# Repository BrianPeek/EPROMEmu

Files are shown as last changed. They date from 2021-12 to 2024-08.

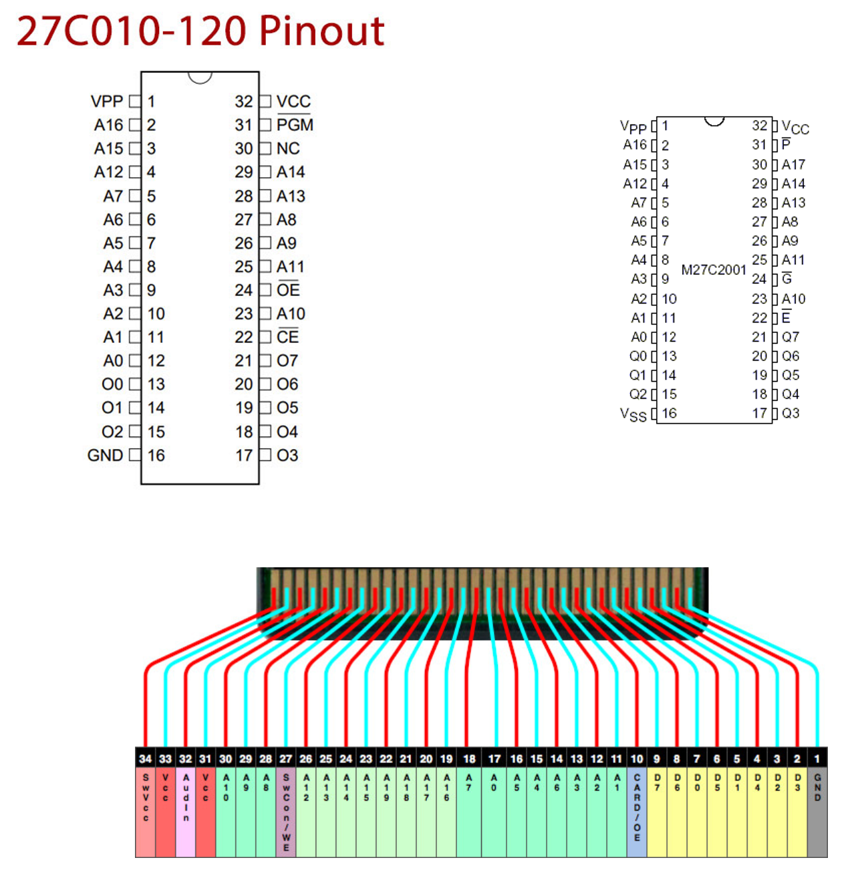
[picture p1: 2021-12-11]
other/pinouts.png

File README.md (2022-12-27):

# EPROMEmu

**!! WARNING: I have no idea what I'm doing !!**

I've decided to make this public in the rare event it might help someone.

This is a very simple, likely very wrong (EP)ROM emulator using a Teensy 4.1 and Arduino/PlatformIO.  It works for my purposes (emulating an EPROM for
use in an Atari Lynx EPROM cartridge), but it it is probably not the "correct" way to design hardware.  I have also used it on Game Gear and Vectrex EPROM cartridges,
but it was not heavily tested.

Please take caution with using anything you see here.  It's my first time using KiCad, my first time designing a PCB, and my first time creating hardware.  Again,
it works for my purposes, but perhaps it'll burn your house down.

Enjoy!

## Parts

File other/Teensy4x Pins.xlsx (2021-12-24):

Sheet: T4
Pin | Name | GPIO | Serial | I2C | SPI | PWM | CAN | Audio | XBAR | FlexIO | Analog | SD
0 | AD_B0_03 | 1.3 | Serial1(6) RX |  | SPI1(3) CS0 | PWM1_X1 | 2_RX |  | IO-17
1 | AD_B0_02 | 1.2 | Serial1(6) TX |  | SPI1(3) MISO | PWM1_X0 | 2_TX |  | IO-16
2 | EMC_04 | 4.4 |  |  |  | PWM4_A2 |  | 2:TX_DATA | IO-06 | 1:4
3 | EMC_05 | 4.5 |  |  |  | PWM4_B2 |  | 2:TX_SYNC | IO-07 | 1:5
4 | EMC_06 | 4.6 |  |  |  | PWM2_A0 |  | 2:TX_BCLK | IO-08 | 1:6
5 | EMC_08 | 4.8 |  |  |  | PWM2_A1 |  | 2:RX_DATA | IO-17 | 1:8
6 | B0_10 | 2.10 |  |  |  | PWM2_A2, QT4_1 |  | 1:TX3_RX1 |  | 2:10
7 | B1_01 | 2.17 | Serial2(4) RX |  |  | PWM1_B3 |  | 1:TX_DATA | IO-15 | 2:17, 3:17
8 | B1_00 | 2.16 | Serial2(4) TX |  |  | PWM1_A3 |  | 1:RX_DATA | IO-14 | 2:16, 3:16
9 | B0_11 | 2.11 |  |  |  | PWM2_B2, QT4_2 |  | 1:TX2_RX2 |  | 2:11
10 | B0_00 | 2.0 |  |  | SPI(4) CS0 | QT1_0 |  | MQS_RIGHT |  | 2:0
11 | B0_02 | 2.2 |  |  | SPI(4) MOSI | QT1_2 | 1_TX |  |  | 2:2
12 | B0_01 | 2.1 |  |  | SPI(4) MISO | QT1_1 |  | MQS_LEFT |  | 2:1
13 | B0_03 | 2.3 |  |  | SPI(4) SCK | QT2_0 | 1_RX |  |  | 2:3
14/A0 | AD_B1_02 | 1.18 | Serial3(2) TX |  |  | QT3_2 |  | SPDIF_OUT |  | 3:2 | A1:7, A2:7
15/A1 | AD_B1_03 | 1.19 | Serial3(2) RX |  |  | QT3_3 |  | SPDIF_IN |  | 3:3 | A1:8, A2:8
16/A2 | AD_B1_07 | 1.23 | Serial4(3) RX | Wire1(3) SCL |  |  |  | SPDIF_EXTCLK |  | 3:7 | A1:12, A2:12
17/A3 | AD_B1_06 | 1.22 | Serial4(3) TX | Wire1(3) SDA |  |  |  | SPDIF_LOCK |  | 3:6 | A1:11, A2:11
18/A4 | AD_B1_01 | 1.17 | Serial3(2) RTS | Wire(1) SDA |  | QT3_1 |  |  |  | 3:1 | A1:6, A2:6
19/A5 | AD_B1_00 | 1.16 | Serial3(2) CTS | Wire(1) SCL |  | QT3_0 |  |  |  | 3:0 | A1:5, A2:5
20/A6 | AD_B1_10 | 1.26 | Serial5(8) TX |  |  |  |  | 1:RX_SYNC |  | 3:10 | A1:15, A2:15
21/A7 | AD_B1_11 | 1.27 | Serial5(8) RX |  |  |  |  | 1:RX_BCLK |  | 3:11 | A1:0, A2:0
22/A8 | AD_B1_08 | 1.24 |  |  |  | PWM4_A0 | 1_TX |  |  | 3:8 | A1:13, A2:13
23/A9 | AD_B1_09 | 1.25 |  |  |  | PWM4_A1 | 1_RX | 1:MCLK |  | 3:9 | A1:14, A2:14
--- | ---- | ---- | ------ | --- | --- | --- | --- | ---- | ---- | ----- | ------
24/A10 | AD_B0_12 | 1.12 | Serial6(1) TX | Wire2(4) SCL |  | PWM1_X2 |  |  |  |  | A1:1
25/A11 | AD_B0_13 | 1.13 | Serial6(1) RX | Wire2(4) SDA |  | PWM1_X3 | GPT1_CLK |  |  |  | A1:2
26/A12 | AD_B1_14 | 1.30 |  |  | SPI1(3) MOSI |  |  | 1:TX_BCLK |  | 3:14 | A2:3
27/A13 | AD_B1_15 | 1.31 |  |  | SPI1(3) SCK |  |  | 1:TX_SYNC |  | 3:15 | A2:4
28 | EMC_32 | 3.18 | Serial7(7) RX |  |  | PWM3_B1
29 | EMC_31 | 4.31 | Serial7(7) TX |  | SPI2(1) CS1 | PWM3_A1
30 | EMC_37 | 3.23 |  |  |  | GPT1_3 | 3_RX | 3:MCLK | IO-23
31 | EMC_36 | 3.22 |  |  |  | GPT1_2 | 3_TX | 3:TX_DATA | IO-22
32 | B0_12 | 2.12 |  |  |  |  |  | 1:TX1_RX3 | IO-10 | 2:12
33 | EMC_07 | 4.7 |  |  |  | PWM2_B0 |  | 2:MCLK | IO-09 | 1:7
34 | SD_B0_03 | 3.15 | Serial5(8) RTS |  | SPI2(1) MISO | PWM1_B1 |  |  | IO-07 |  |  | DATA1
35 | SD_B0_02 | 3.14 | Serial5(8) CTS |  | SPI2(1) MOSI | PWM1_A1 |  |  | IO-06 |  |  | DATA0
36 | SD_B0_01 | 3.13 |  | Wire1(3) SDA | SPI2(1) CS0 | PWM1_B0 |  |  | IO-05 |  |  | CLK
37 | SD_B0_00 | 3.12 |  | Wire1(3) SCL | SPI2(1) SCK | PWM1_A0 |  |  | IO-04 |  |  | CMD
38 | SD_B0_05 | 3.17 | Serial5(8) RX |  | SPI2(1) B_DQS | PWM1_B2 |  |  | IO-09 |  |  | DATA3
39 | SD_B0_04 | 3.16 | Serial5(8) TX |  | SPI2(1) B_SSO_B | PWM1_A2 |  |  | IO-08 |  |  | DATA2

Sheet: T4 - GPIO
Pin | Name | GPIO | Serial | I2C | SPI | PWM | CAN | Audio | XBAR | FlexIO | Analog | SD
1 | AD_B0_02 | 1.02 | Serial1(6) TX |  | SPI1(3) MISO | PWM1_X0 | 2_TX |  | IO-16
0 | AD_B0_03 | 1.03 | Serial1(6) RX |  | SPI1(3) CS0 | PWM1_X1 | 2_RX |  | IO-17
24/A10 | AD_B0_12 | 1.12 | Serial6(1) TX | Wire2(4) SCL |  | PWM1_X2 |  |  |  |  | A1:1
25/A11 | AD_B0_13 | 1.13 | Serial6(1) RX | Wire2(4) SDA |  | PWM1_X3 | GPT1_CLK |  |  |  | A1:2
19/A5 | AD_B1_00 | 1.16 | Serial3(2) CTS | Wire(1) SCL |  | QT3_0 |  |  |  | 3:0 | A1:5, A2:5
18/A4 | AD_B1_01 | 1.17 | Serial3(2) RTS | Wire(1) SDA |  | QT3_1 |  |  |  | 3:1 | A1:6, A2:6
14/A0 | AD_B1_02 | 1.18 | Serial3(2) TX |  |  | QT3_2 |  | SPDIF_OUT |  | 3:2 | A1:7, A2:7
15/A1 | AD_B1_03 | 1.19 | Serial3(2) RX |  |  | QT3_3 |  | SPDIF_IN |  | 3:3 | A1:8, A2:8
17/A3 | AD_B1_06 | 1.22 | Serial4(3) TX | Wire1(3) SDA |  |  |  | SPDIF_LOCK |  | 3:6 | A1:11, A2:11
16/A2 | AD_B1_07 | 1.23 | Serial4(3) RX | Wire1(3) SCL |  |  |  | SPDIF_EXTCLK |  | 3:7 | A1:12, A2:12
22/A8 | AD_B1_08 | 1.24 |  |  |  | PWM4_A0 | 1_TX |  |  | 3:8 | A1:13, A2:13
23/A9 | AD_B1_09 | 1.25 |  |  |  | PWM4_A1 | 1_RX | 1:MCLK |  | 3:9 | A1:14, A2:14
20/A6 | AD_B1_10 | 1.26 | Serial5(8) TX |  |  |  |  | 1:RX_SYNC |  | 3:10 | A1:15, A2:15
21/A7 | AD_B1_11 | 1.27 | Serial5(8) RX |  |  |  |  | 1:RX_BCLK |  | 3:11 | A1:0, A2:0
26/A12 | AD_B1_14 | 1.30 |  |  | SPI1(3) MOSI |  |  | 1:TX_BCLK |  | 3:14 | A2:3
27/A13 | AD_B1_15 | 1.31 |  |  | SPI1(3) SCK |  |  | 1:TX_SYNC |  | 3:15 | A2:4
10 | B0_00 | 2.00 |  |  | SPI(4) CS0 | QT1_0 |  | MQS_RIGHT |  | 2:0
12 | B0_01 | 2.01 |  |  | SPI(4) MISO | QT1_1 |  | MQS_LEFT |  | 2:1
11 | B0_02 | 2.02 |  |  | SPI(4) MOSI | QT1_2 | 1_TX |  |  | 2:2
13 | B0_03 | 2.03 |  |  | SPI(4) SCK | QT2_0 | 1_RX |  |  | 2:3
6 | B0_10 | 2.10 |  |  |  | PWM2_A2, QT4_1 |  | 1:TX3_RX1 |  | 2:10
9 | B0_11 | 2.11 |  |  |  | PWM2_B2, QT4_2 |  | 1:TX2_RX2 |  | 2:11
32 | B0_12 | 2.12 |  |  |  |  |  | 1:TX1_RX3 | IO-10 | 2:12
8 | B1_00 | 2.16 | Serial2(4) TX |  |  | PWM1_A3 |  | 1:RX_DATA | IO-14 | 2:16, 3:16
7 | B1_01 | 2.17 | Serial2(4) RX |  |  | PWM1_B3 |  | 1:TX_DATA | IO-15 | 2:17, 3:17
37 | SD_B0_00 | 3.12 |  | Wire1(3) SCL | SPI2(1) SCK | PWM1_A0 |  |  | IO-04 |  |  | CMD
36 | SD_B0_01 | 3.13 |  | Wire1(3) SDA | SPI2(1) CS0 | PWM1_B0 |  |  | IO-05 |  |  | CLK
35 | SD_B0_02 | 3.14 | Serial5(8) CTS |  | SPI2(1) MOSI | PWM1_A1 |  |  | IO-06 |  |  | DATA0
34 | SD_B0_03 | 3.15 | Serial5(8) RTS |  | SPI2(1) MISO | PWM1_B1 |  |  | IO-07 |  |  | DATA1
39 | SD_B0_04 | 3.16 | Serial5(8) TX |  | SPI2(1) B_SSO_B | PWM1_A2 |  |  | IO-08 |  |  | DATA2
38 | SD_B0_05 | 3.17 | Serial5(8) RX |  | SPI2(1) B_DQS | PWM1_B2 |  |  | IO-09 |  |  | DATA3
28 | EMC_32 | 3.18 | Serial7(7) RX |  |  | PWM3_B1
31 | EMC_36 | 3.22 |  |  |  | GPT1_2 | 3_TX | 3:TX_DATA | IO-22
30 | EMC_37 | 3.23 |  |  |  | GPT1_3 | 3_RX | 3:MCLK | IO-23
2 | EMC_04 | 4.04 |  |  |  | PWM4_A2 |  | 2:TX_DATA | IO-06 | 1:4
3 | EMC_05 | 4.05 |  |  |  | PWM4_B2 |  | 2:TX_SYNC | IO-07 | 1:5
4 | EMC_06 | 4.06 |  |  |  | PWM2_A0 |  | 2:TX_BCLK | IO-08 | 1:6
33 | EMC_07 | 4.07 |  |  |  | PWM2_B0 |  | 2:MCLK | IO-09 | 1:7
5 | EMC_08 | 4.08 |  |  |  | PWM2_A1 |  | 2:RX_DATA | IO-17 | 1:8
29 | EMC_31 | 4.31 | Serial7(7) TX |  | SPI2(1) CS1 | PWM3_A1

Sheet: T4 card like
Audio | Prop | Native | GPIO | Audio | FlexIO | Xbar | I2C | CAN | SPI | Serial | Analog | PWM | Digital |  |  | Digital | PWM | Analog | Serial | SPI | CAN | I2C | Xbar | FlexIO | Audio | GPIO | Native | Prop | Audio
G | GND |  |  |  |  |  |  |  |  |  | GND |  |  |  |  | Vin |  |  |  |  |  |  |  |  |  |  |  | 5V
 |  | AD_B0_03 | 1.3 |  |  | 17 |  | RX2 | CS1 | RX1 |  | 1X1 | 0 |  |  | GND |  |  |  |  |  |  |  |  |  |  |  | G | G
 |  | AD_B0_02 | 1.2 |  |  | 16 |  | TX2 | MISO1 | TX1 |  | 1X0 | 1 |  |  | 3.3V 250mA max |  |  |  |  |  |  |  |  |  |  |  | 3V | 3.3
 | S | EMC_04 | 4.4 | O2 | 1:4 | 6 |  |  |  |  |  | 4A2 | 2 |  |  | 23 | 4A1 | A9 |  |  | RX1 |  |  | 3:9 | MCL1 | 1.25 | AD-B1_09 |  | A
M |  | EMC_05 | 4.5 | LR2 | 1:5 | 7 |  |  |  |  |  | 4B2 | 3 |  |  | 22 | 4A0 | A8 |  |  | TX1 |  |  | 3:08:00 |  | 1.24 | AD_B1_08
A |  | EMC_06 | 4.6 | BCL2 | 1:6 | 8 |  |  |  |  |  | 2A0 | 4 |  |  | 21 |  | A7 | RX5 |  |  |  |  | 3:11:00 | BCL1 | 1.27 | AD_B1_11 |  | A
A | A-EN | EMC_08 | 4.8 | IN2 | 1:8 | 17 |  |  |  |  |  | 2A1 | 5 |  |  | 20 |  | A6 | TX5 |  |  |  |  | 3:10:00 | LRC1 | 1.26 | AD_B1_10 |  | A
 | M-CS | B0_10 | 2.10 | O1D | 2:10 |  |  |  |  |  |  | 2A2, Q41 | 6 |  |  | 19 | Q30 | A5 | CTS3 |  |  | SCL0 |  | 3:00:00 |  | 1.16 | AD_B1_00 | S | C
 | L-EN | B1_01 | 2.17 | O1A | 2:17, 3:17 | 15 |  |  |  | RX2 |  | 1B3 | 7 |  |  | 18 | Q31 | A4 |  |  |  | SDA0 |  | 3:01:00 |  | 1.17 | AD_B1_01 | S | C
 |  | B1_00 | 2.16 | IN1 | 2:16, 3:16 | 14 | sda0 |  |  | TX2 |  | 1A3 | 8 |  |  | 17 |  | A3 | TX4 |  |  | SDA1 |  | 3:06:00 |  | 1.22 | AD_B1_06
 |  | B0_11 | 2.11 | O1C | 2:11 |  |  |  |  |  |  | 2B2,Q42 | 9 |  |  | 16 |  | A2 | RX4 |  |  | SCL1 |  | 3:07:00 |  | 1.23 | AD_B1_07
S |  | B0_00 | 2.0 | MQR | 2:0 |  |  |  | CS0 |  |  | Q10 | 10 |  |  | 15 | Q33 | A1 | RX3 |  |  |  |  | 3:03:00 | SPDI | 1.19 | AD_B1_03 |  | V
SM | M/L | B0_02 | 2.2 |  | 2:2 |  |  | TX1 | MOSI0 |  |  | Q12 | 11 |  |  | 14 | Q32 | A0 | TX3 |  |  |  |  | 3:02:00 | SPDO | 1.18 | AD_B1_02
SM | M | B0_01 | 2.1 | MQL | 2:1 |  |  |  | MISO0 |  |  | Q11 | 12 |  |  | 13 | Q20 | LED |  | SCK0 | rx1 |  |  | 2:03:00 |  | 2.3 | B0_03 | M | SM
 |  |  |  |  |  |  |  |  |  | Bottom SMT Pins
 |  | AD_B0_12 | 1.12 |  |  |  | SCL2 |  |  | TX6 | A10-1 | 1X2 | 24 |  |  | 25 | 1X3 | A11-1 | RX6 |  |  | SDA2 |  |  |  | 1.13 | AD_B0_13
 |  | AD_B1_14 | 1.30 |  | 3:14 |  |  |  | MOSI1 |  | A12-2 |  | 26 |  |  | 27 |  | A13-2 |  | SCK1 |  |  |  | 3:15 |  | 1.31 | AD_B1_15
 |  | EMC_32 | 3.18 |  |  |  |  |  |  | RX7 |  | 3B1 | 28 |  |  | 29 | 3A1 |  | TX7 |  |  |  |  |  |  | 4.31 | EMC_31
 |  | EMC_37 | 3.23 |  |  | 23 |  | RX3 |  |  |  | G13 | 30 |  |  | 31 | G12 |  |  |  | TX3 |  | 22 |  |  | 3.22 | EMC_36
 |  | B0_12 | 2.12 | O1B | 2:12:00 | 10 |  |  |  |  |  |  | 32 |  |  | 33 | 2B0 |  |  |  | TX1 |  | 9 | 1:7 | MCL2 | 4.7 | EMC_07
 |  |  |  |  |  |  |  |  |  | Bottom SDIO Pins
 |  | SD_B0_03 | 3.15 |  | DATA1 | 7 |  |  | MISO2 |  |  | 1B1 | 34 | ______| | |_____
 |  | SD_B0_02 | 3.14 |  | DATA0 | 6 |  |  | MOSI2 | CTS5 |  | 1A1 | 35 | _______| | |_______
 |  |  |  |  |  |  |  |  |  |  | GND |  |  | _________| | |_______
 |  | SD_B0_01 | 3.13 |  | CLK | 5 | SDA1 |  | CS2 |  |  | 1B0 | 36 | __________| | |___________
 |  |  |  |  |  |  |  |  |  |  | 3.3V 250mA max
 |  | SD_B0_00 | 3.12 |  | CMD | 4 | SCL1 |  | SCK2 |  |  | 1A0 | 37
 |  | SD_B0_05 | 3.17 |  | DATA3 | 9 |  |  |  | RX5 |  | 1B2 | 38
 |  | SD_B0_04 | 3.16 |  | DATA2 | 8 |  |  |  | TX5 |  | 1A2 | 39

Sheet: T4.1
Pin | Name | GPIO | Serial | I2C | SPI | PWM | CAN | Audio | XBAR | FlexIO | Analog | SD/CSI/LCD
0 | AD_B0_03 | 1.3 | Serial1(6) RX |  | SPI1(3) CS0 | PWM1_X1 | 2_RX |  | IO-17
1 | AD_B0_02 | 1.2 | Serial1(6) TX |  | SPI1(3) MISO | PWM1_X0 | 2_TX |  | IO-16
2 | EMC_04 | 4.4 |  |  |  | PWM4_A2 |  | 2:TX_DATA | IO-06 | 1:4
3 | EMC_05 | 4.5 |  |  |  | PWM4_B2 |  | 2:TX_SYNC | IO-07 | 1:5
4 | EMC_06 | 4.6 |  |  |  | PWM2_A0 |  | 2:TX_BCLK | IO-08 | 1:6
5 | EMC_08 | 4.8 |  |  |  | PWM2_A1 |  | 2:RX_DATA | IO-17 | 1:8
6 | B0_10 | 2.10 |  |  |  | PWM2_A2, QT4_1 |  | 1:TX3_RX1 |  | 2:10
7 | B1_01 | 2.17 | Serial2(4) RX |  |  | PWM1_B3 |  | 1:TX_DATA | IO-15 | 2:17, 3:17
8 | B1_00 | 2.16 | Serial2(4) TX |  |  | PWM1_A3 |  | 1:RX_DATA | IO-14 | 2:16, 3:16
9 | B0_11 | 2.11 |  |  |  | PWM2_B2,QT4_2 |  | 1:TX2_RX2 |  | 2:11
10 | B0_00 | 2.0 |  |  | SPI(4) CS0 | QT1_0 |  | MQS_RIGHT |  | 2:0
11 | B0_02 | 2.2 |  |  | SPI(4) MOSI | QT1_2 | 1_TX |  |  | 2:2
12 | B0_01 | 2.1 |  |  | SPI(4) MISO | QT1_1 |  | MQS_LEFT |  | 2:1
13 | B0_03 | 2.3 |  |  | SPI(4) SCK | QT2_0 | 1_RX |  |  | 2:3
14/A0 | AD_B1_02 | 1.18 | Serial3(2) TX |  |  | QT3_2 |  | SPDIF_OUT |  | 3:2 | A1:7, A2:7
15/A1 | AD_B1_03 | 1.19 | Serial3(2) RX |  |  | QT3_3 |  | SPDIF_IN |  | 3:3 | A1:8, A2:8
16/A2 | AD_B1_07 | 1.23 | Serial4(3) RX | Wire1(3) SCL |  |  |  | SPDIF_EXTCLK |  | 3:7 | A1:12, A2:12 | CSI_HSYNC
17/A3 | AD_B1_06 | 1.22 | Serial4(3) TX | Wire1(3) SDA |  |  |  | SPDIF_LOCK |  | 3:6 | A1:11, A2:11 | CSI_VSYNC
18/A4 | AD_B1_01 | 1.17 | Serial3(2) RTS | Wire(1) SDA |  | QT3_1 |  |  |  | 3:1 | A1:6, A2:6
19/A5 | AD_B1_00 | 1.16 | Serial3(2) CTS | Wire(1) SCL |  | QT3_0 |  |  |  | 3:0 | A1:5, A2:5
20/A6 | AD_B1_10 | 1.26 | Serial5(8) TX |  |  |  |  | 1:RX_SYNC |  | 3:10 | A1:15, A2:15 | CSI_D7
21/A7 | AD_B1_11 | 1.27 | Serial5(8) RX |  |  |  |  | 1:RX_BCLK |  | 3:11 | A1:0, A2:0 | CSI_D6
22/A8 | AD_B1_08 | 1.24 |  |  |  | PWM4_A0 | 1_TX |  |  | 3:8 | A1:13, A2:13 | CSI_D9
23/A9 | AD_B1_09 | 1.25 |  |  |  | PWM4_A1 | 1_RX | 1:MCLK |  | 3:9 | A1:14, A2:14 | CSI_D8
--- | ---- | ---- | ------ | --- | --- | --- | --- | ---- | ---- | ----- | ------
24/A10 | AD_B0_12 | 1.12 | Serial6(1) TX | Wire2(4) SCL |  | PWM1_X2 |  |  |  |  | A1:1
25/A11 | AD_B0_13 | 1.13 | Serial6(1) RX | Wire2(4) SDA |  | PWM1_X3 | GPT1_CLK |  |  |  | A1:2
26/A12 | AD_B1_14 | 1.30 |  |  | SPI1(3) MOSI |  |  | 1:TX_BCLK |  | 3:14 | A2:3 | CSI_D3
27/A13 | AD_B1_15 | 1.31 |  |  | SPI1(3) SCK |  |  | 1:TX_SYNC |  | 3:15 | A2:4 | CSI_D2
28 | EMC_32 | 3.18 | Serial7(7) RX |  |  | PWM3_B1
29 | EMC_31 | 4.31 | Serial7(7) TX |  | SPI2(1) CS1 | PWM3_A1
30 | EMC_37 | 3.23 |  |  |  | GPT1_3 | 3_RX | 3:MCLK | IO-23
31 | EMC_36 | 3.22 |  |  |  | GPT1_2 | 3_TX | 3:TX_DATA | IO-22
32 | B0_12 | 2.12 |  |  |  |  |  | 1:TX1_RX3 | IO-10 | 2:12
33 | EMC_07 | 4.7 |  |  |  | PWM2_B0 |  | 2:MCLK | IO-09 | 1:7
34 | B1_13 | 2.29 | Serial8(5) RX |  |  |  |  |  |  | 2:29,3:29
35 | B1_12 | 2.28 | Serial8(5) TX |  |  |  |  |  |  | 2:28,3:28
36 | B1_02 | 2.18 |  |  | SPI(4) CS2 | PWM2_A3 |  | 1:TX_BCLK | IO-16 | 2:18,3:18
37 | B1_03 | 2.19 |  |  | SPI(4) CS1 | PWM2_B3 |  | 1:TX_SYNC | IO-17 | 2:19,3:19
38/A14 | AD_B1_12 | 1.28 |  |  | SPI1(3) CS0 |  |  | 1:rx_data |  | 3:12 | A2:1 | CSI_D5
39/A5 | AD_B1_13 | 1.29 |  |  | SPI1(3) MISO |  |  | 1:tx_data |  | 3:13 | A2:2 | CSI_D4
40/A16 | AD_B1_04 | 1.20 |  |  |  |  |  |  |  | 3:4 | A1:9,A2:9 | CSI_PIXCLK
41/A17 | AD_B1_05 | 1.21 |  |  |  | GPT2_1 |  |  |  | 3:5 | A1:10,A2:10 | CSI_MCLK
SD Pins - Cable connector(T4 34-39)
42 | SD_B0_03 | 3.15 | Serial5(8) RTS |  | SPI2(1) MISO | PWM1_B1 |  |  | IO-07 |  |  | DATA1
43 | SD_B0_02 | 3.14 | Serial5(8) CTS |  | SPI2(1) MOSI | PWM1_A1 |  |  | IO-06 |  |  | DATA0
44 | SD_B0_01 | 3.13 |  | Wire1(3) SDA | SPI2(1) CS0 | PWM1_B0 |  |  | IO-05 |  |  | CLK
45 | SD_B0_00 | 3.12 |  | Wire1(3) SCL | SPI2(1) SCK | PWM1_A0 |  |  | IO-04 |  |  | CMD
46 | SD_B0_05 | 3.17 | Serial5(8) RX |  | FLEXSPI B_DQS | PWM1_B2 |  |  | IO-09 |  |  | DATA3
47 | SD_B0_04 | 3.16 | Serial5(8) TX |  | FLEXSPI B_SSO_B | PWM1_A2 |  |  | IO-08 |  |  | DATA2
Bottom Memory Connectors
48 | EMC_24 | 4:24 | Serial8(5) RX |  | FLEXSPI2_A_SS0_B | PWM1_B0
49 | EMC_27 | 4:27 | Serial8(5) RTS |  | FLEXSPI2_A_DATA01, SPI2(1) SCK | PWM1_A2 |  |  |  | 1:13
50 | EMC_28 | 4:28 | Serial8(5) CTS |  | FLEXSPI2_A_DATA02, SPI2(1) MOSI | PWM1_B2 |  |  |  | 1:14
51 | EMC_22 | 4:22 |  | Wire1(3) SCL | FLEXSPI2_A_SS1_B | PWM3_B3, QT2_3
52 | EMC_26 | 4:26 | Serial1(6) RX |  | FLEXSPI2_A_DATA00 | PWM1_B1 |  |  |  | 1:12
53 | EMC_25 | 4:25 | Serial1(6) TX |  | FLEXSPI2_A_SCLK | PWM1_A1
54 | EMC_29 | 4:29 | Serial1(6) RTS |  | FLEXSPI2_A_DATA03, SPI2(1) MISO | PWM3_A0 |  |  |  | 1:15

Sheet: T4.1 MUX
Pin | Name | ALT0 | ALt1 | ALT2 | ALT3 | ALT4 | Alt5 | ALT6 | ALT7 | ALT8 | ALT9
0 | AD_B0_03 | FLEXCAN2_RX | XBAR1_INOUT17 | LPUART6_RX | USB_OTG1_OC | FLEXPWM1_PWMX01 | GPIO1_IO03 | REF_CLK_24M | LPSPI3_PCS0
1 | AD_B0_02 | FLEXCAN2_TX | XBAR1_INOUT16 | LPUART6_TX | USB_OTG1_PWR | LEXPWM1_PWMX0 | GPIO1_IO02 | LPI2C1_HREQ | LPSPI3_SDI
2 | EMC_04 | SEMC_DATA04 | FLEXPWM4_PWMA02 | SAI2_TX_DATA | XBAR1_INOUT06 | FLEXIO1_FLEXIO04 | GPIO4_IO04
3 | EMC_05 | SEMC_DATA05 | FLEXPWM4_PWMB0 | SAI2_TX_SYNC | XBAR1_INOUT07 | FLEXIO1_FLEXIO05 | GPIO4_IO05
4 | EMC_06 | SEMC_DATA06 | FLEXPWM2_PWMA00 | SAI2_TX_BCLK | XBAR1_INOUT08 | FLEXIO1_FLEXIO06 | GPIO4_IO06
5 | EMC_08 | SEMC_DM00 | FLEXPWM2_PWMA01 | SAI2_RX_DATA | XBAR1_INOUT17 | FLEXIO1_FLEXIO08 | GPIO4_IO08
6 | B0_10 | LCD_DATA06 | QTIMER4_TIMER1 | FLEXPWM2_PWMA02 | SAI1_TX_DATA03 | FLEXIO2_FLEXIO10 | GPIO2_IO10 | SRC_BOOT_CFG06 |  | ENET2_CRS
7 | B1_01 | LCD_DATA13 | XBAR1_INOUT15 | LPUART4_RX | SAI1_TX_DATA00 | FLEXIO2_FLEXIO17 | GPIO2_IO17 | FLEXPWM1_PWMB03 |  | ENET2_RDATA00 | FLEXIO3_FLEXIO17
8 | B1_00 | LCD_DATA12 | XBAR1_INOUT14 | LPUART4_TX | SAI1_RX_DATA00 | FLEXIO2_FLEXIO16 | GPIO2_IO16 | FLEXPWM1_PWMA03 |  | ENET2_RX_ER | FLEXIO3_FLEXIO16
9 | B0_11 | LCD_DATA07 | QTIMER4_TIMER2 | FLEXPWM2_PWMB02 | SAI1_TX_DATA02 | FLEXIO2_FLEXIO11 | GPIO2_IO11 | SRC_BOOT_CFG07 |  | ENET2_COL
10 | B0_00 | LCD_CLK | QTIMER1_TIMER0 | MQS_RIGHT | LPSPI4_PCS0 | FLEXIO2_FLEXIO00 | GPIO2_IO00 | SEMC_CSX01 |  | ENET2_MDC
11 | B0_02 | LCD_HSYNC | QTIMER1_TIMER2 | FLEXCAN1_TX | LPSPI4_SDO | FLEXIO2_FLEXIO02 | GPIO2_IO02 | SEMC_CSX03 |  | ENET2_1588_EVENT0_OUT
12 | B0_01 | LCD_ENABLE | QTIMER1_TIMER1 | MQS_LEFT | LPSPI4_SDI | FLEXIO2_FLEXIO01 | GPIO2_IO01 | SEMC_CSX02 |  | ENET2_MDIO
13 | B0_03 | LCD_VSYNC | QTIMER2_TIMER0 | FLEXCAN1_RX | LPSPI4_SCK | FLEXIO2_FLEXIO03 | GPIO2_IO03 | WDOG2_RESET_B_DEB |  | ENET2_1588_EVENT0_IN
14/A0 | AD_B1_02 | USB_OTG1_ID | QTIMER3_TIMER2 | LPUART2_TX | SPDIF_OUT | ENET_1588_EVENT2_OUT | GPIO1_IO18 | USDHC1_CD_B | KPP_ROW06 | GPT2_CLK | FLEXIO3_FLEXIO02
15/A1 | AD_B1_03 | USB_OTG1_OC | QTIMER3_TIMER3 | LPUART2_RX | SPDIF_IN | ENET_1588_EVENT2_IN | GPIO1_IO19 | USDHC2_CD_B | KPP_COL06 | GPT2_CAPTURE1 | FLEXIO3_FLEXIO03
16/A2 | AD_B1_07 | FLEXSPIB_DATA00 | LPI2C3_SCL | LPUART3_RX | SPDIF_EXT_CLK | CSI_HSYNC | GPIO1_IO23 | USDHC2_DATA3 | KPP_COL04 | GPT2_COMPARE3 | FLEXIO3_FLEXIO07
17/A3 | AD_B1_06 | FLEXSPIB_DATA01 | LPI2C3_SDA | LPUART3_TX | SPDIF_LOCK | CSI_VSYNC | GPIO1_IO22 | USDHC2_DATA2 | KPP_ROW04 | GPT2_COMPARE2 | FLEXIO3_FLEXIO06
18/A4 | AD_B1_01 | USB_OTG1_PWR | QTIMER3_TIMER1 | LPUART2_RTS_B | LPI2C1_SDA | CCM_PMIC_READY | GPIO1_IO17 | USDHC1_VSELECT | KPP_COL07 | ENET2_1588_EVENT0_IN | FLEXIO3_FLEXIO01
19/A5 | AD_B1_00 | USB_OTG2_ID | QTIMER3_TIMER0 | LPUART2_CTS_B | LPI2C1_SCL | WDOG1_B | GPIO1_IO16 | USDHC1_W | KPP_ROW07 | ENET2_1588_EVENT0_OUT | FLEXIO3_FLEXIO00
20/A6 | AD_B1_10 | FLEXSPIA_DATA03 | WDOG1_B | LPUART8_TX | SAI1_RX_SYNC | CSI_DATA07 | GPIO1_IO26 | USDHC2_WP | KPP_ROW02 | ENET2_1588_EVENT1_OUT | FLEXIO3_FLEXIO10
21/A7 | AD_B1_11 | FLEXSPIA_DATA02 | EWM_OUT_B | LPUART8_RX | SAI1_RX_BCL | CSI_DATA06 | GPIO1_IO27 | USDHC2_RESET_B | KPP_COL02 | ENET2_1588_EVENT1_IN | FLEXIO3_FLEXIO11
22/A8 | AD_B1_08 | FLEXSPIA_SS1_B | FLEXPWM4_PWMA00 | FLEXCAN1_TX | CCM_PMIC_READY | CSI_DATA09 | GPIO1_IO24 | USDHC2_CMD | KPP_ROW03 |  | FLEXIO3_FLEXIO08
23/A9 | AD_B1_09 | FLEXSPIA_DQS | FLEXPWM4_PWMA01 | FLEXCAN1_RX | SAI1_MCLK | CSI_DATA08 | GPIO1_IO25 | USDHC2_CLK | KPP_COL03 |  | FLEXIO3_FLEXIO09
24/A10 | AD_B0_12 | LPI2C4_SCL | CCM_PMIC_READY | LPUART1_TX | WDOG2_WDOG_B | FLEXPWM1_PWMX02 | GPIO1_IO12 | ENET_1588_EVENT1_OUT | NMI_GLUE_NMI
25/A11 | AD_B0_13 | LPI2C4_SDA | GPT1_CLK | LPUART1_RX | EWM_OUT_B | FLEXPWM1_PWMX03 | GPIO1_IO13 | ENET_1588_EVENT1_IN | REF_CLK_24M
26/A12 | AD_B1_14 | FLEXSPIA_SCLK | ACMP_OUT02 | LPSPI3_SDO | SAI1_TX_BCLK | CSI_DATA03 | GPIO1_IO30 | USDHC2_DATA6 | KPP_ROW00 | ENET2_1588_EVENT3_OUT | FLEXIO3_FLEXIO14
27/A13 | AD_B1_15 | FLEXSPIA_SS0_B | ACMP_OUT03 | LPSPI3_SCK | SAI1_TX_SYNC | CSI_DATA02 | GPIO1_IO31 | USDHC2_DATA7 | KPP_COL00 | ENET2_1588_EVENT3_IN | FLEXIO3_FLEXIO15
28 | EMC_32 | SEMC_DATA10 | FLEXPWM3_PWMB01 | LPUART7_RX | CCM_PMIC_RDY | CSI_DATA21 | GPIO3_IO18 |  |  | ENET2_TX_EN
29 | EMC_31 | SEMC_DATA09 | FLEXPWM3_PWMA01 | LPUART7_TX | LPSPI1_PCS1 | CSI_DATA22 | GPIO4_IO31 |  |  | ENET2_TDATA01
30 | EMC_37 | SEMC_DATA15 | XBAR1_IN23 | GPT1_COMPARE3 | SAI3_MCLK | CSI_DATA16 | GPIO3_IO23 | USDHC2_WP |  | ENET2_RX_EN | FLEXCAN3_RX
31 | EMC_36 | SEMC_DATA14 | XBAR1_IN22 | GPT1_COMPARE2 | SAI3_TX_DATA | CSI_DATA17 | GPIO3_IO22 | USDHC1_WP |  | ENET2_RDATA01 | FLEXCAN3_TX
32 | B0_12 | LCD_DATA08 | XBAR1_INOUT10 | ARM_TRACE_CLK | SAI1_TX_DATA01 | FLEXIO2_FLEXIO12 | GPIO2_IO12 | SRC_BOOT_CFG08 |  | ENET2_TDATA00
33 | EMC_07 | SEMC_DATA07 | FLEXPWM2_PWMB00 | SAI2_MCLK | XBAR1_INOUT09 | FLEXIO1_FLEXIO07 | GPIO4_IO07
34 | B1_13 | WDOG1_B | LPUART5_RX | CSI_VSYNC | ENET_1588_EVENT0_OUT | FLEXIO2_FLEXIO29 | GPIO2_IO29 | USDHC1_WP |  | SEMC_DQS4 | FLEXIO3_FLEXIO29
35 | B1_12 |  | LPUART5_TX | CSI_PIXCLK | ENET_1588_EVENT0_IN | FLEXIO2_FLEXIO28 | GPIO2_IO28 | USDHC1_CD_B |  |  | FLEXIO3_FLEXIO28
36 | B1_02 | LCD_DATA14 | XBAR1_INOUT16 | LPSPI4_PCS2 | SAI1_TX_BCLK | FLEXIO2_FLEXIO18 | GPIO2_IO18 | FLEXPWM2_PWMA03 |  | ENET2_RDATA01 | FLEXIO3_FLEXIO18
37 | B1_03 | LCD_DATA15 | XBAR1_INOUT17 | LPSPI4_PCS1 | SAI1_TX_SYNC | FLEXIO2_FLEXIO19 | GPIO2_IO19 | FLEXPWM2_PWMB03 |  | ENET2_RX_EN | FLEXIO3_FLEXIO19
38/A14 | AD_B1_12 | FLEXSPIA_DATA01 | ACMP_OUT00 | LPSPI3_PCS0 | SAI1_RX_DATA00 | CSI_DATA05 | GPIO1_IO28 | USDHC2_DATA4 | KPP_ROW01 | ENET2_1588_EVENT2_OUT | FLEXIO3_FLEXIO12
39/A5 | AD_B1_13 | FLEXSPIA_DATA00 | ACMP_OUT01 | LPSPI3_SDI | SAI1_TX_DATA00 | CSI_DATA04 | GPIO1_IO29 | USDHC2_DATA5 | KPP_COL01 | ENET2_1588_EVENT2_IN | FLEXIO3_FLEXIO13
40/A16 | AD_B1_04 | FLEXSPIB_DATA03 | ENET_MDC | LPUART3_CTS_B | SPDIF_SR_CLK | CSI_PIXCLK | GPIO1_IO20 | USDHC2_DATA0 | KPP_ROW05 | GPT2_CAPTURE2 | FLEXIO3_FLEXIO04
41/A17 | AD_B1_05 | FLEXSPIB_DATA02 | ENET_MDIO | LPUART3_RTS_B | SPDIF_OUT | CSI_MCLK | GPIO1_IO21 | USDHC2_DATA1 | KPP_COL05 | GPT2_COMPARE1 | FLEXIO3_FLEXIO05
42 | SD_B0_03 | USDHC1_DATA1 | FLEXPWM1_PWMB01 | LPUART8_RTS_B | XBAR1_INOUT07 | LPSPI1_SDI | GPIO3_IO15 |  |  | ENET2_RDATA00 | SEMC_CLK6
43 | SD_B0_02 | USDHC1_DATA0 | FLEXPWM1_PWMA01 | LPUART8_CTS_B | XBAR1_INOUT06 | LPSPI1_SDO | GPIO3_IO14 |  |  | ENET2_RX_ER | SEMC_CLK5
44 | SD_B0_01 | USDHC1_CLK | FLEXPWM1_PWMB00 | LPI2C3_SDA | XBAR1_INOUT05 | LPSPI1_PCS0 | GPIO3_IO13 | FLEXSPIB_SS1_B |  | ENET2_TX_CLK | ENET2_REF_CLK2
45 | SD_B0_00 | USDHC1_CMD | FLEXPWM1_PWMA00 | LPI2C3_SCL | XBAR1_INOUT04 | LPSPI1_SCK | GPIO3_IO12 | FLEXSPIA_SS1_B |  | ENET2_TX_EN | SEMC_DQS4
46 | SD_B0_05 | USDHC1_DATA3 | FLEXPWM1_PWMB02 | LPUART8_RX | XBAR1_INOUT09 | FLEXSPIB_DQS | GPIO3_IO17 | CCM_CLKO2 |  | ENET2_RX_EN
47 | SD_B0_04 | USDHC1_DATA2 | FLEXPWM1_PWMA02 | LPUART8_TX | XBAR1_INOUT08 | FLEXSPIB_SS0_B | GPIO3_IO16 | CCM_CLKO1 |  | ENET2_RDATA01
48 | EMC_24 | SEMC_CAS | FLEXPWM1_PWMB00 | LPUART5_RX | ENET_TX_EN | GPT1_CAPTURE1 | GPIO4_IO24 |  |  | FLEXSPI2_A_SS0_B
49 | EMC_27 | SEMC_CKE | FLEXPWM1_PWMA02 | LPUART5_RTS_B | LPSPI1_SCK | FLEXIO1_FLEXIO13 | GPIO4_IO27 |  |  | FLEXSPI2_A_DATA01
50 | EMC_28 | SEMC_WE | FLEXPWM1_PWMB02 | LPUART5_CTS_B | LPSPI1_SDO | FLEXIO1_FLEXIO14 | GPIO4_IO28 |  |  | FLEXSPI2_A_DATA02
51 | EMC_22 | SEMC_BA1 | FLEXPWM3_PWMB03 | LPI2C3_SCL | ENET_TDATA00 | QTIMER2_TIMER3 | GPIO4_IO22 |  |  | FLEXSPI2_A_SS1_B of
52 | EMC_26 | SEMC_CLK | FLEXPWM1_PWMB01 | LPUART6_RX | ENET_RX_ER | FLEXIO1_FLEXIO12 | GPIO4_IO26 |  |  | FLEXSPI2_A_DATA00
53 | EMC_25 | SEMC_RAS | FLEXPWM1_PWMA01 | LPUART6_TX | ENET_TX_CLK | ENET_REF_CLK | GPIO4_IO25 |  |  | FLEXSPI2_A_SCLK
54 | EMC_29 | SEMC_CS0 | FLEXPWM3_PWMA00 | LPUART6_RTS_B | LPSPI1_SDI | FLEXIO1_FLEXIO15 | GPIO4_IO29 |  |  | FLEXSPI2_A_DATA03
IOMUXC_xxx_SELECT_INPUT
Column1 | Column2 | Column3 | Column4 | Column5 | Column6 | Column7 | Column8 | Column9 | Column10 | Column11 | Column12
0 | AD_B0_03 | FLEXCAN2_RX | IOMUXC_XBAR1_IN17_SELECT_INPUT=0x1 | IOMUXC_LPUART6_RX_SELECT_INPUT=1 | USB_OTG1_OC | FLEXPWM1_PWMX01 | GPIO1_IO03 | REF_CLK_24M | LPSPI3_PCS0
1 | AD_B0_02 | FLEXCAN2_TX | XBAR1_INOUT16 | IOMUXC_LPUART6_TX_SELECT_INPUT=1 | USB_OTG1_PWR | LEXPWM1_PWMX0 | GPIO1_IO02 | LPI2C1_HREQ | LPSPI3_SDI
2 | EMC_04 | SEMC_DATA04 | FLEXPWM4_PWMA02 | SAI2_TX_DATA | IOMUXC_XBAR1_IN06_SELECT_INPUT=0x0 | FLEXIO1_FLEXIO04 | GPIO4_IO04
3 | EMC_05 | SEMC_DATA05 | FLEXPWM4_PWMB0 | SAI2_TX_SYNC | IOMUXC_XBAR1_IN07_SELECT_INPUT=0x0 | FLEXIO1_FLEXIO05 | GPIO4_IO05
4 | EMC_06 | SEMC_DATA06 | FLEXPWM2_PWMA00 | SAI2_TX_BCLK | IOMUXC_XBAR1_IN08_SELECT_INPUT=0x0 | FLEXIO1_FLEXIO06 | GPIO4_IO06
5 | EMC_08 | SEMC_DM00 | FLEXPWM2_PWMA01 | SAI2_RX_DATA | IOMUXC_XBAR1_IN17_SELECT_INPUT=0x0 | FLEXIO1_FLEXIO08 | GPIO4_IO08
6 | B0_10 | LCD_DATA06 | QTIMER4_TIMER1 | FLEXPWM2_PWMA02 | SAI1_TX_DATA03 | FLEXIO2_FLEXIO10 | GPIO2_IO10 | SRC_BOOT_CFG06 |  | ENET2_CRS
7 | B1_01 | LCD_DATA13 | XBAR1_INOUT15 | IOMUXC_LPUART4_RX_SELECT_INPUT=2 | SAI1_TX_DATA00 | FLEXIO2_FLEXIO17 | GPIO2_IO17 | FLEXPWM1_PWMB03 |  | ENET2_RDATA00 | FLEXIO3_FLEXIO17
8 | B1_00 | LCD_DATA12 | XBAR1_INOUT14 | IOMUXC_LPUART4_TX_SELECT_INPUT=2 | SAI1_RX_DATA00 | FLEXIO2_FLEXIO16 | GPIO2_IO16 | FLEXPWM1_PWMA03 |  | ENET2_RX_ER | FLEXIO3_FLEXIO16
9 | B0_11 | LCD_DATA07 | QTIMER4_TIMER2 | FLEXPWM2_PWMB02 | SAI1_TX_DATA02 | FLEXIO2_FLEXIO11 | GPIO2_IO11 | SRC_BOOT_CFG07 |  | ENET2_COL
10 | B0_00 | LCD_CLK | QTIMER1_TIMER0 | MQS_RIGHT | LPSPI4_PCS0 | FLEXIO2_FLEXIO00 | GPIO2_IO00 | SEMC_CSX01 |  | ENET2_MDC
11 | B0_02 | LCD_HSYNC | QTIMER1_TIMER2 | FLEXCAN1_TX | LPSPI4_SDO | FLEXIO2_FLEXIO02 | GPIO2_IO02 | SEMC_CSX03 |  | ENET2_1588_EVENT0_OUT
12 | B0_01 | LCD_ENABLE | QTIMER1_TIMER1 | MQS_LEFT | LPSPI4_SDI | FLEXIO2_FLEXIO01 | GPIO2_IO01 | SEMC_CSX02 |  | ENET2_MDIO
13 | B0_03 | LCD_VSYNC | QTIMER2_TIMER0 | FLEXCAN1_RX | LPSPI4_SCK | FLEXIO2_FLEXIO03 | GPIO2_IO03 | WDOG2_RESET_B_DEB |  | ENET2_1588_EVENT0_IN
14/A0 | AD_B1_02 | USB_OTG1_ID | QTIMER3_TIMER2 | IOMUXC_LPUART2_TX_SELECT_INPUT=1 | SPDIF_OUT | ENET_1588_EVENT2_OUT | GPIO1_IO18 | USDHC1_CD_B | KPP_ROW06 | GPT2_CLK | FLEXIO3_FLEXIO02
15/A1 | AD_B1_03 | USB_OTG1_OC | QTIMER3_TIMER3 | IOMUXC_LPUART2_RX_SELECT_INPUT=1 | SPDIF_IN | ENET_1588_EVENT2_IN | GPIO1_IO19 | USDHC2_CD_B | KPP_COL06 | GPT2_CAPTURE1 | FLEXIO3_FLEXIO03
16/A2 | AD_B1_07 | FLEXSPIB_DATA00 | LPI2C3_SCL | IOMUXC_LPUART3_RX_SELECT_INPUT=0 | SPDIF_EXT_CLK | CSI_HSYNC | GPIO1_IO23 | USDHC2_DATA3 | KPP_COL04 | GPT2_COMPARE3 | FLEXIO3_FLEXIO07
17/A3 | AD_B1_06 | FLEXSPIB_DATA01 | LPI2C3_SDA | IOMUXC_LPUART3_TX_SELECT_INPUT=0 | SPDIF_LOCK | CSI_VSYNC | GPIO1_IO22 | USDHC2_DATA2 | KPP_ROW04 | GPT2_COMPARE2 | FLEXIO3_FLEXIO06
18/A4 | AD_B1_01 | USB_OTG1_PWR | QTIMER3_TIMER1 | LPUART2_RTS_B | LPI2C1_SDA | CCM_PMIC_READY | GPIO1_IO17 | USDHC1_VSELECT | KPP_COL07 | ENET2_1588_EVENT0_IN | FLEXIO3_FLEXIO01
19/A5 | AD_B1_00 | USB_OTG2_ID | QTIMER3_TIMER0 | LPUART2_CTS_B | LPI2C1_SCL | WDOG1_B | GPIO1_IO16 | USDHC1_W | KPP_ROW07 | ENET2_1588_EVENT0_OUT | FLEXIO3_FLEXIO00
20/A6 | AD_B1_10 | FLEXSPIA_DATA03 | WDOG1_B | IOMUXC_LPUART8_TX_SELECT_INPUT=1 | SAI1_RX_SYNC | CSI_DATA07 | GPIO1_IO26 | USDHC2_WP | KPP_ROW02 | ENET2_1588_EVENT1_OUT | FLEXIO3_FLEXIO10
21/A7 | AD_B1_11 | FLEXSPIA_DATA02 | EWM_OUT_B | IOMUXC_LPUART8_RX_SELECT_INPUT=1 | SAI1_RX_BCL | CSI_DATA06 | GPIO1_IO27 | USDHC2_RESET_B | KPP_COL02 | ENET2_1588_EVENT1_IN | FLEXIO3_FLEXIO11
22/A8 | AD_B1_08 | FLEXSPIA_SS1_B | FLEXPWM4_PWMA00 | FLEXCAN1_TX | CCM_PMIC_READY | CSI_DATA09 | GPIO1_IO24 | USDHC2_CMD | KPP_ROW03 |  | FLEXIO3_FLEXIO08
23/A9 | AD_B1_09 | FLEXSPIA_DQS | FLEXPWM4_PWMA01 | FLEXCAN1_RX | SAI1_MCLK | CSI_DATA08 | GPIO1_IO25 | USDHC2_CLK | KPP_COL03 |  | FLEXIO3_FLEXIO09
24/A10 | AD_B0_12 | LPI2C4_SCL | CCM_PMIC_READY | LPUART1_TX | WDOG2_WDOG_B | FLEXPWM1_PWMX02 | GPIO1_IO12 | ENET_1588_EVENT1_OUT | NMI_GLUE_NMI
25/A11 | AD_B0_13 | LPI2C4_SDA | GPT1_CLK | LPUART1_RX | EWM_OUT_B | FLEXPWM1_PWMX03 | GPIO1_IO13 | ENET_1588_EVENT1_IN | REF_CLK_24M
26/A12 | AD_B1_14 | FLEXSPIA_SCLK | ACMP_OUT02 | LPSPI3_SDO | SAI1_TX_BCLK | CSI_DATA03 | GPIO1_IO30 | USDHC2_DATA6 | KPP_ROW00 | ENET2_1588_EVENT3_OUT | FLEXIO3_FLEXIO14
27/A13 | AD_B1_15 | FLEXSPIA_SS0_B | ACMP_OUT03 | LPSPI3_SCK | SAI1_TX_SYNC | CSI_DATA02 | GPIO1_IO31 | USDHC2_DATA7 | KPP_COL00 | ENET2_1588_EVENT3_IN | FLEXIO3_FLEXIO15
28 | EMC_32 | SEMC_DATA10 | FLEXPWM3_PWMB01 | IOMUXC_LPUART7_RX_SELECT_INPUT=1 | CCM_PMIC_RDY | CSI_DATA21 | GPIO3_IO18 |  |  | ENET2_TX_EN
29 | EMC_31 | SEMC_DATA09 | FLEXPWM3_PWMA01 | OMUXC_LPUART7_TX_SELECT_INPUT=1 | LPSPI1_PCS1 | CSI_DATA22 | GPIO4_IO31 |  |  | ENET2_TDATA01
30 | EMC_37 | SEMC_DATA15 | IOMUXC_XBAR1_IN23_SELECT_INPUT=0x0 | GPT1_COMPARE3 | SAI3_MCLK | CSI_DATA16 | GPIO3_IO23 | USDHC2_WP |  | ENET2_RX_EN | FLEXCAN3_RX
31 | EMC_36 | SEMC_DATA14 | IOMUXC_XBAR1_IN22_SELECT_INPUT=0x0 | GPT1_COMPARE2 | SAI3_TX_DATA | CSI_DATA17 | GPIO3_IO22 | USDHC1_WP |  | ENET2_RDATA01 | FLEXCAN3_TX
32 | B0_12 | LCD_DATA08 | XBAR1_INOUT10 | ARM_TRACE_CLK | SAI1_TX_DATA01 | FLEXIO2_FLEXIO12 | GPIO2_IO12 | SRC_BOOT_CFG08 |  | ENET2_TDATA00
33 | EMC_07 | SEMC_DATA07 | FLEXPWM2_PWMB00 | SAI2_MCLK | IOMUXC_XBAR1_IN09_SELECT_INPUT=0x0 | FLEXIO1_FLEXIO07 | GPIO4_IO07
34 | B1_13 | WDOG1_B | IOMUXC_LPUART5_RX_SELECT_INPUT=1 | CSI_VSYNC | ENET_1588_EVENT0_OUT | FLEXIO2_FLEXIO29 | GPIO2_IO29 | USDHC1_WP |  | SEMC_DQS4 | FLEXIO3_FLEXIO29
35 | B1_12 |  | IOMUXC_LPUART5_TX_SELECT_INPUT=1 | CSI_PIXCLK | ENET_1588_EVENT0_IN | FLEXIO2_FLEXIO28 | GPIO2_IO28 | USDHC1_CD_B |  |  | FLEXIO3_FLEXIO28
36 | B1_02 | LCD_DATA14 | XBAR1_INOUT16 | LPSPI4_PCS2 | SAI1_TX_BCLK | FLEXIO2_FLEXIO18 | GPIO2_IO18 | FLEXPWM2_PWMA03 |  | ENET2_RDATA01 | FLEXIO3_FLEXIO18
37 | B1_03 | LCD_DATA15 | IOMUXC_XBAR1_IN17_SELECT_INPUT=0x3 | LPSPI4_PCS1 | SAI1_TX_SYNC | FLEXIO2_FLEXIO19 | GPIO2_IO19 | FLEXPWM2_PWMB03 |  | ENET2_RX_EN | FLEXIO3_FLEXIO19
38/A14 | AD_B1_12 | FLEXSPIA_DATA01 | ACMP_OUT00 | LPSPI3_PCS0 | SAI1_RX_DATA00 | CSI_DATA05 | GPIO1_IO28 | USDHC2_DATA4 | KPP_ROW01 | ENET2_1588_EVENT2_OUT | FLEXIO3_FLEXIO12
39/A5 | AD_B1_13 | FLEXSPIA_DATA00 | ACMP_OUT01 | LPSPI3_SDI | SAI1_TX_DATA00 | CSI_DATA04 | GPIO1_IO29 | USDHC2_DATA5 | KPP_COL01 | ENET2_1588_EVENT2_IN | FLEXIO3_FLEXIO13
40/A16 | AD_B1_04 | FLEXSPIB_DATA03 | ENET_MDC | LPUART3_CTS_B | SPDIF_SR_CLK | CSI_PIXCLK | GPIO1_IO20 | USDHC2_DATA0 | KPP_ROW05 | GPT2_CAPTURE2 | FLEXIO3_FLEXIO04
41/A17 | AD_B1_05 | FLEXSPIB_DATA02 | ENET_MDIO | LPUART3_RTS_B | SPDIF_OUT | CSI_MCLK | GPIO1_IO21 | USDHC2_DATA1 | KPP_COL05 | GPT2_COMPARE1 | FLEXIO3_FLEXIO05
42 | SD_B0_03 | USDHC1_DATA1 | FLEXPWM1_PWMB01 | LPUART8_RTS_B | IOMUXC_XBAR1_IN07_SELECT_INPUT=0x1 | LPSPI1_SDI | GPIO3_IO15 |  |  | ENET2_RDATA00 | SEMC_CLK6
43 | SD_B0_02 | USDHC1_DATA0 | FLEXPWM1_PWMA01 | LPUART8_CTS_B | IOMUXC_XBAR1_IN06_SELECT_INPUT=0x1 | LPSPI1_SDO | GPIO3_IO14 |  |  | ENET2_RX_ER | SEMC_CLK5
44 | SD_B0_01 | USDHC1_CLK | FLEXPWM1_PWMB00 | LPI2C3_SDA | IOMUXC_XBAR1_IN05_SELECT_INPUT=0x1 | LPSPI1_PCS0 | GPIO3_IO13 | FLEXSPIB_SS1_B |  | ENET2_TX_CLK | ENET2_REF_CLK2
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

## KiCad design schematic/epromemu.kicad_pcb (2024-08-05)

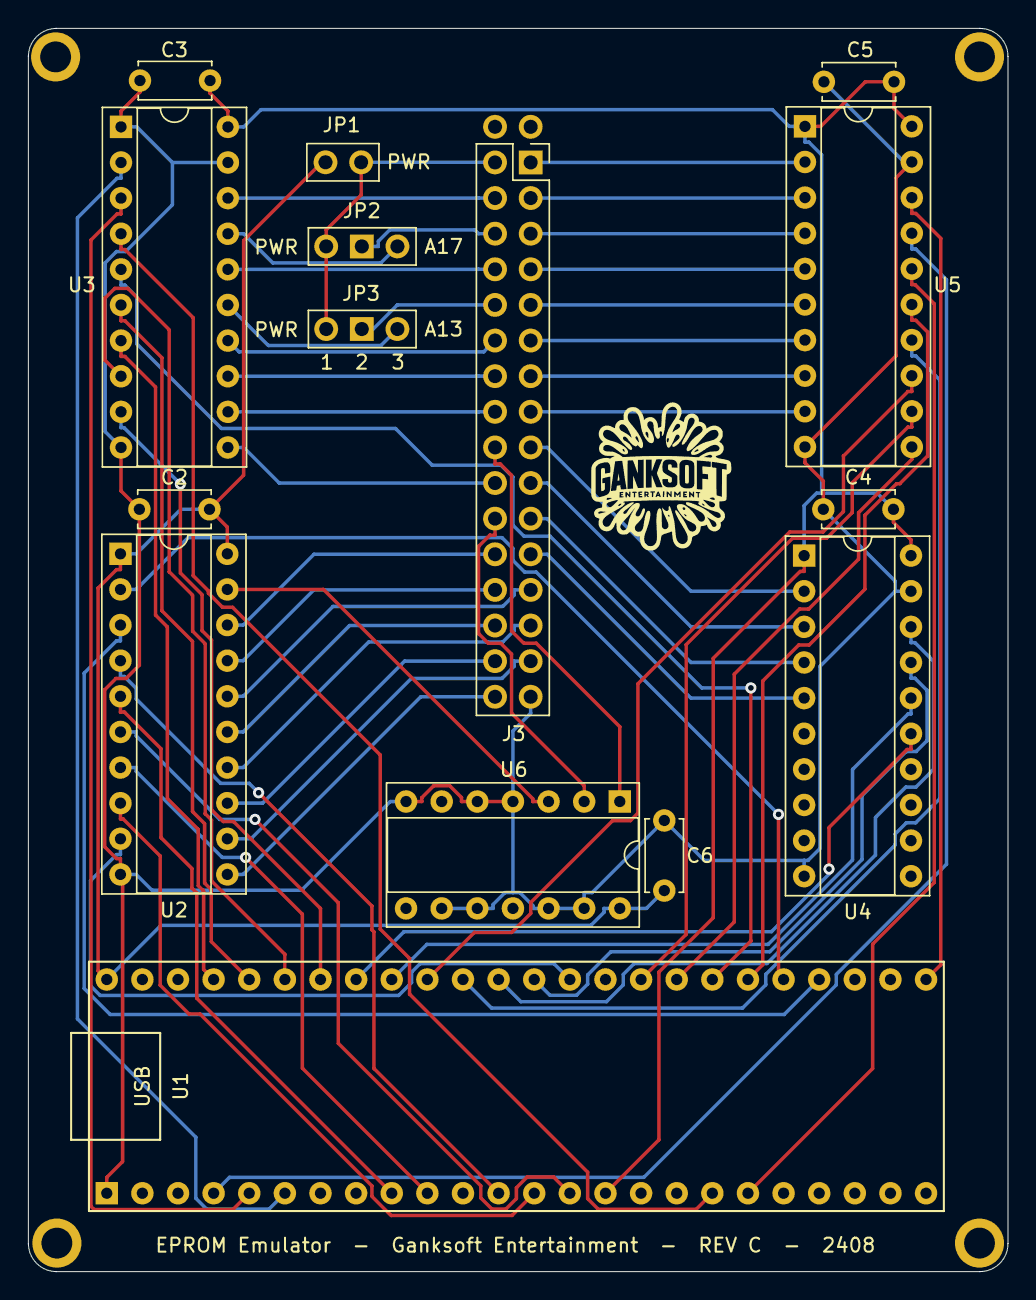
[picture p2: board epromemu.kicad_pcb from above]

Board: 2 copper layers, 69.9 x 88.6 mm, 20 parts (0 on the bottom side), 65 nets.

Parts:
C2, C3, C4, C5, C6: 0.1uf; C_Disc_D5.0mm_W2.5mm_P5.00mm
GanksoftLogo: LOGO; GanksoftLogo
H1, H2, H3, H4: MountingHole; MountingHole_2.2mm_M2_ISO7380_Pad
J3: EPROM Connector; PinHeader_2x16_P2.54mm_Vertical
JP1: PWR; PinHeader_1x02_P2.54mm_Vertical
JP2: A17; PinHeader_1x03_P2.54mm_Vertical
JP3: A13; PinHeader_1x03_P2.54mm_Vertical
U1: Teensy4.1; Teensy41
U2, U3, U4, U5: 74HC245; DIP-20_W7.62mm_Socket
U6: 74HC32; DIP-14_W7.62mm_Socket

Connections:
+3V3: C3.1, C4.1, C5.1, U1.15 (3V3), U3.20 (VCC), U4.1 (A->B), U4.20 (VCC), U5.1 (A->B), U5.20 (VCC)
+5V: C2.1, C6.1, JP1.2 (B), U1.48 (VIN), U2.1 (A->B), U2.20 (VCC), U6.14 (VCC)
A0_3V3: U1.41 (19_A5_SCL), U4.15 (B3)
A0_5V: J3.12, U4.5 (A3)
A1_3V3: U1.40 (18_A4_SDA), U4.16 (B2)
A1_5V: J3.11, U4.4 (A2)
A2_3V3: U1.36 (14_A0_TX3_SPDIF_OUT), U4.17 (B1)
A2_5V: J3.10, U4.3 (A1)
A3_3V3: U1.37 (15_A1_RX3_SPDIF_IN), U4.18 (B0)
A3_5V: J3.9, U4.2 (A0)
A4_3V3: U1.32 (40_A16), U5.11 (B7)
A4_5V: J3.8, U5.9 (A7)
A5_3V3: U1.33 (41_A17), U5.12 (B6)
A5_5V: J3.7, U5.8 (A6)
A6_3V3: U1.39 (17_A3_TX4_SDA1), U5.13 (B5)
A6_5V: J3.6, U5.7 (A5)
A7_3V3: U1.38 (16_A2_RX4_SCL1), U5.14 (B4)
A7_5V: J3.5, U5.6 (A4)
A8_3V3: U1.44 (22_A8_CTX1), U3.6 (A4)
A8_5V: J3.27, U3.14 (B4)
A9_3V3: U1.45 (23_A9_CRX1_MCLK1), U3.7 (A5)
A9_5V: J3.26, U3.13 (B5)
A10_3V3: U1.42 (20_A6_TX5_LRCLK1), U3.9 (A7)
A10_5V: J3.23, U3.11 (B7)
A11_3V3: U1.43 (21_A7_RX5_BCLK1), U3.8 (A6)
A11_5V: J3.25, U3.12 (B6)
A12_3V3: U1.30 (38_CS1_IN1), U5.15 (B3)
A12_5V: J3.4, U5.5 (A3)
A13_3V3: U1.31 (39_MISO1_OUT1A), U3.5 (A3)
A13_5V: JP3.3 (B), U3.15 (B3)
A14_3V3: U1.18 (26_A12_MOSI1), U3.4 (A2)
A14_5V: J3.29, U3.16 (B2)
A15_3V3: U1.19 (27_A13_SCK1), U5.16 (B2)
A15_5V: J3.3, U5.4 (A2)
A16_3V3: U1.4 (2_OUT2), U5.17 (B1)
A16_5V: J3.2, U5.3 (A1)
A17_3V3: U1.5 (3_LRCLK2), U3.3 (A1)
A17_5V: JP2.3 (B), U3.17 (B1)
A18_3V3: U1.6 (4_BCLK2), U3.2 (A0)
A18_5V: J3.31, U3.18 (B0)
A19_3V3: U1.25 (33_MCLK2), U5.18 (B0)
A19_5V: J3.1, U5.2 (A0)
CE_5V: J3.22, U6.2
D0_3V3: U1.12 (10_CS_MQSR), U2.4 (A2)
D0_5V: J3.13, U2.16 (B2)
D1_3V3: U1.14 (12_MISO_MQSL), U2.6 (A4)
D1_5V: J3.14, U2.14 (B4)
D2_3V3: U1.13 (11_MOSI_CTX1), U2.8 (A6)
D2_5V: J3.15, U2.12 (B6)
D3_3V3: U1.35 (13_SCK_LED), U2.9 (A7)
D3_5V: J3.17, U2.11 (B7)
D4_3V3: U1.10 (8_TX2_IN1), U2.7 (A5)
D4_5V: J3.18, U2.13 (B5)
D5_3V3: U1.9 (7_RX2_OUT1A), U2.5 (A3)
D5_5V: J3.19, U2.15 (B3)
D6_3V3: U1.28 (36_CS), U2.3 (A1)
D6_5V: J3.20, U2.17 (B1)
D7_3V3: U1.29 (37_CS), U2.2 (A0)
D7_5V: J3.21, U2.18 (B0)
GND: C2.2, C3.2, C4.2, C5.2, C6.2, J3.16, U1.1 (GND), U2.10 (GND), U3.1 (A->B), U3.10 (GND), U3.19 (CE), U4.10 (GND), U4.19 (CE), U5.10 (GND), U5.19 (CE), U6.4, U6.5, U6.7 (GND), U6.9, U6.10, U6.12, U6.13
JP1_PWR: J3.32, JP1.1 (A), JP2.1 (A), JP3.1 (A)
unnamed: J3.28, JP3.2 (C)
unnamed: J3.30, JP2.2 (C)
unnamed: U2.19 (CE), U6.3
OE_5V: J3.24, U6.1

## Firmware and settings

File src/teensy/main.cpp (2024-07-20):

#include <Arduino.h>
#include <SPI.h>
#include <SD.h>

// FLASHMEM
// DMAMEM
// PROGMEM

enum eMode : unsigned char
{
	m27C256 = 1,
	m27C010 = 2,
	m27C020 = 3,
};

#define ROM_BUFFER_LEN (256*1024)
EXTMEM char buffer[ROM_BUFFER_LEN];
const char *filename = "rom.bin";
eMode mode = m27C020;
Stream* stream;

int32_t inPins[] = { 19,18,14,15,40,41,17,16,22,23,20,21,38,39,26,27,24,25,-1 };
int32_t outPins[] = { 10,12,11,13,8,7,36,37,-1 };

void readData(Stream* s)
{
	const int length = 1024;
	char buff[length];
	int total = 0;

	mode = (eMode)s->read();

	memset(buffer, 0xFF, ROM_BUFFER_LEN);

	size_t read = 0;
	char* p = buffer;

	do
	{
		memset(buff, 0, length);

		read = s->readBytes(buff, length);

		if(read > 0)
		{
			memcpy(p, buff, read);
			p += read;
			total += read;
		}
	}
	while(read != 0);

	SD.remove(filename);

	File f = SD.open(filename, O_WRITE);
	f.write(buffer, total);
	f.close();
}

void setPinMode(int32_t* pins, int32_t direction)
{
	for(int i = 0; pins[i] != -1; i++)
		pinMode(pins[i], direction);
}

void setup()
{
	mode = m27C256;

	setPinMode(inPins, INPUT);
	setPinMode(outPins, OUTPUT);
	GPIO7_DR = 0;

	SD.begin(BUILTIN_SDCARD);

	if(SD.exists(filename))
	{
		File f = SD.open(filename, O_READ);
		size_t size = f.size();
		f.read(buffer, size);
		f.close();

		if(size > 32*1024)
			mode = m27C010;

		if(size > 128*1024)
			mode = m27C020;
	}

	Serial.begin(115200);
	Serial1.begin(3000000);
}

void loop()
{
	uint32_t io6 = GPIO6_DR;
	uint32_t outb = 0;

	// read address pins
	uint32_t addr = 0;

	switch(mode)
	{
		// 256Kbit, 32KB, 0x0000-0x7FFF
		case m27C256:
			addr = ((io6 >> 16) & 0x7FFF);
			break;

		// 1Mbit, 128KB, 0x00000-0x1FFFF
		case m27C010:
			addr = ((io6 >> 16) & 0xFFFF) | ((io6 & 0x1000) << 4);
			break;

		// 2Mbit, 256KB, 0x00000-0x3FFFF
		case m27C020:
		default:
			addr = ((io6 >> 16) & 0xFFFF) | ((io6 & 0x3000) << 4);
			break;
	}

	// get byte at addr
	char b = buffer[addr];

	// set data pins
	outb = ((b & 0x0F) << 0) | ((b & 0xF0) << 12);
	GPIO7_DR = outb;

	// read file from either serial port, if available
	if(Serial.available())
		readData(&Serial);

	if(Serial1.available())
		readData(&Serial1);
}



// addr
// GPIO6-16 -> 19 A0
// GPIO6-17 -> 18 A1
// GPIO6-18 -> 14 A2
// GPIO6-19 -> 15 A3
// GPIO6-20 -> 40 A4
// GPIO6-21 -> 41 A5
// GPIO6-22 -> 17 A6
// GPIO6-23 -> 16 A7
// GPIO6-24 -> 22 A8
// GPIO6-25 -> 23 A9
// GPIO6-26 -> 20 A10
// GPIO6-27 -> 21 A11
// GPIO6-28 -> 38 A12
// GPIO6-29 -> 39 A13
// GPIO6-30 -> 26 A14
// GPIO6-31 -> 27 A15
// GPIO9-04 -> 02 A16
// GPIO9-05 -> 03 A17
// GPIO9-06 -> 04 A18
// GPIO9-07 -> 33 A19

// data
// GPIO7-00 -> 10 D0
// GPIO7-01 -> 12 D1
// GPIO7-02 -> 11 D2
// GPIO7-03 -> 13 D3
// GPIO7-16 -> 08 D4
// GPIO7-17 -> 07 D5
// GPIO7-18 -> 36 D6
// GPIO7-19 -> 37 D7

// the rest
// GPIO6-12 -> 24
// GPIO6-13 -> 25
// GPIO6-02 -> 01
// GPIO6-03 -> 00

// GPIO7-10 -> 06
// GPIO7-11 -> 09
// GPIO7-12 -> 32
// GPIO7-28 -> 35
// GPIO7-29 -> 34

// GPIO8-12 -> 45
// GPIO8-13 -> 44
// GPIO8-14 -> 43
// GPIO8-15 -> 42
// GPIO8-16 -> 47
// GPIO8-17 -> 46
// GPIO8-18 -> 28
// GPIO8-22 -> 31
// GPIO8-23 -> 30

// GPIO9-08 -> 05
// GPIO9-22 -> 51
// GPIO9-24 -> 48
// GPIO9-25 -> 53
// GPIO9-26 -> 52
// GPIO9-27 -> 49
// GPIO9-28 -> 50
// GPIO9-29 -> 54
// GPIO9-31 -> 29

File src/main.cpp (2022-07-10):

#include <Arduino.h>
#include <SPI.h>
#include <SD.h>

// forced to a 2mbit eprom
// FLASHMEM
// DMAMEM
// PROGMEM

#define ROM_BUFFER_LEN (256*1024)
char buffer[ROM_BUFFER_LEN];
const char *filename = "rom.bin";

int32_t inPins[] = { 19,18,14,15,40,41,17,16,22,23,20,21,38,39,26,27,24,25,-1 };
int32_t outPins[] = { 10,12,11,13,8,7,36,37,-1 };

void readFile(int port)
{
	const int length = 1024;
	char buff[length];

	memset(buffer, 0, ROM_BUFFER_LEN);

	size_t read = 0;
	size_t total = 0;
	char* p = buffer;

	do
	{
		memset(buff, 0, length);

		switch(port)
		{
			case 0:
				read = Serial.readBytes(buff, length);
				break;
			case 1:
				read = Serial1.readBytes(buff, length);
				break;		
		}

		total += read;
		if(read > 0)
		{
			memcpy(p, buff, read);
			p += read;
		}
	}
	while(read != 0);

	// on GG (and lynx?) top address bit gets stuck high (?) so mirror to upper region too?
	if(total == 131072)
		memcpy(p, buffer, 131072);

	SD.remove(filename);

	File f = SD.open(filename, O_WRITE);
	f.write(buffer, ROM_BUFFER_LEN);
	f.close();
}

void setPinMode(int32_t* pins, int32_t direction)
{
	for(int i = 0; pins[i] != -1; i++)
		pinMode(pins[i], direction);
}

void setup()
{
	setPinMode(inPins, INPUT);
	setPinMode(outPins, OUTPUT);
	GPIO7_DR = 0;

	SD.begin(BUILTIN_SDCARD);

	if(SD.exists(filename))
	{
		File f = SD.open(filename, O_READ);
		f.read(buffer, f.size());
		f.close();
	}

	Serial.begin(115200);
	Serial1.begin(3000000);
}

void loop()
{
	uint32_t io6 = GPIO6_DR;
	uint32_t outb = 0;

	// read address pins
	uint32_t addr = ((io6 >> 16) & 0xFFFF) | ((io6 & 0x3000) << 4);

	// get byte at addr
	char b = buffer[addr];

	// set data pins
	outb = ((b & 0x0F) << 0) | ((b & 0xF0) << 12);
	GPIO7_DR = outb;

	// read file from either serial port, if available
	if(Serial.available())
		readFile(0);

	if(Serial1.available())
		readFile(1);
}

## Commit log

2021-12-11 v1 of board, about to change it...
    [LynxEPROMPins.xlsx, epromemu.csv, epromemu.dsn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]
2021-12-11 remove ignored files
    [epromemu.csv, epromemu.dsn]
2021-12-27 submitted v0.1
    [epromemu.kicad_pcb, epromemu.sch]
2021-12-28 update code
    [LynxEPROMPins.xlsx]
2021-12-29 update to v6
    [epromemu.kicad_pcb, epromemu.kicad_sch]
2022-01-02 v0.2 updates
    [LynxEPROMPins.xlsx, epromemu.kicad_pcb, epromemu.kicad_sch]
2022-01-03 v0.2 in progress...
    [epromemu.kicad_pcb, epromemu.kicad_sch]
2022-06-27 v2 updates
    [epromemu.kicad_pcb, epromemu.kicad_sch]
2022-07-16 starting v0.3
    [epromemu.kicad_pcb, epromemu.kicad_sch]
2022-10-20 add pdf schematic
2022-10-21 remove unused files
    [epromemu.sch]
2024-07-20 a complete v3?
    [epromemu.kicad_pcb, epromemu.kicad_sch]
2024-07-26 mounting holes
    [epromemu.kicad_pcb, epromemu.kicad_sch]
2024-08-05 Rev C schem/pcb
    [epromemu.kicad_pcb, epromemu.kicad_sch]
2024-08-06 remove old schematic, it's in git history
    [epromemu.kicad_pcb, epromemu.kicad_sch]
